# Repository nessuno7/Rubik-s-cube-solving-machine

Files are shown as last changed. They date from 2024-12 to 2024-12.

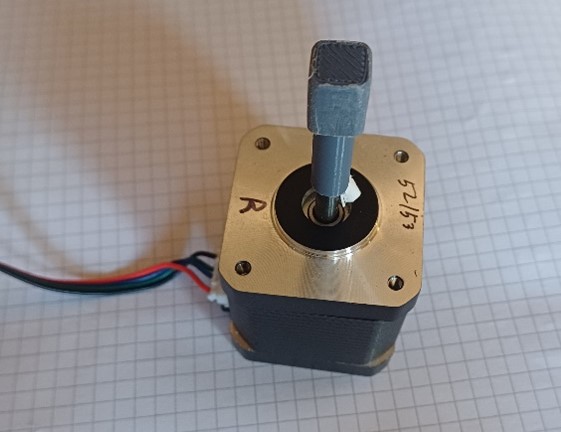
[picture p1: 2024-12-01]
CAD_design/motor_attachment_2.jpg

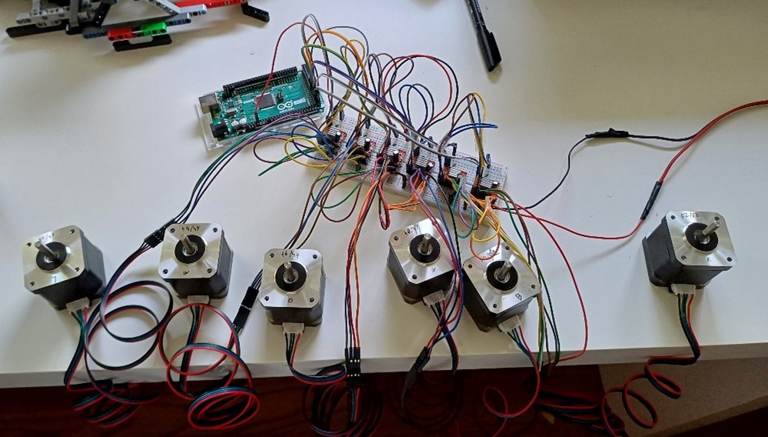
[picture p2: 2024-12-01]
Electronics/wiring_image.jpg

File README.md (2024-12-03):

# Rubik's cube solving machine
The machine solves the Rubik's cube by using the CFOP method, which method allows to solve any scrambled Rubik's cube with 60~100 moves. More information regarding the code in CFOP_algorithm/CFOP_readme.md\
\
The machine's structure is made of a Lego structure to hold the motors into place and 3D printed parts to attach the motors to the centre of the Rubik's cube. More information regarding the structure in CAD_design/CAD_readme.md\
\
The electronics of the machine consist of 6 stepper motors controlled with an Arduino Mega. More information regarding the electronics in Electronics/electronics_readme.md\
\
The code used for Arduino Mega is found in the Arduino_code folder. More information regarding the code in Arduino_code/arduino_readme.md\
\
The machine has two modes of use:
- The code gives prints a random scramble and the CFOP solution to such scramble to the terminal
- The user inputs all the colors of the already scrambles cube in a particular order, and the code prints the solution to the terminal

To run the machine, the Arduino_code needs to be run on an Arduino Mega, while the F2L algorithm needs to be run from the advanced_method.cpp file.\
On the arduino IDE the serial monitor has to be openend to copy and paste the move solutions from the terminal to the serial monitor.

Personal Info:
- name: Nicola Chiandetti
- email: nichiandetti@gmail.com

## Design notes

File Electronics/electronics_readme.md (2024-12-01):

# Electronics
The Rubik’s cube solving machine consist of 6 stepper motors controlled through the A4988 stepper motor driver and the Arduino Mega 2560 R3 board. The schematics of the circuits are shown in the Schematic_rubik-cube-machine.pdf file.\
\
Stepper motors were used as they provided very precise 90° and 180° turns. The model used is the NEMA 17 with 59 Ncm torque.\
\
Each driver needs two separate power supplies: 5V operating voltage with low current and 12V 2A max current for the motor. The VDD of the 6 drivers was connected in parallel with the Arduino 5V output. The VMOT of the 6 drivers was connected in parallel by an external power supply of 12V 10A (max). A capacitor (16V 100 uF) wired in parallel to each driver was also used to prevent voltage spikes to damage the driver and the motor. NEMA 17 59 Ncm has a max operating current of 2A, so the max current was adjusted to 1.8~1.5 A with the potentiometer screw.\
\
By using the A4988 stepper motor driver only two digital pins are needed to control each motor (one step pin and and one direction pin), meaning that only 12 digital pins are needed in total to control the whole machine. This makes it possible to operate the machine also with other small processors, such as the Arduino Uno.\
\
No PCB was used due to the cost of producing and shipping, the wiring is still on a breadboard.

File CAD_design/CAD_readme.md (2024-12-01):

# CAD design
The machine involves a Lego structure, built using Lego pieces from old Lego technic sets, that holds the 6 stepper motors together and 3D printed parts used to connect the stepper motors to the centre of the Cube.\
\
All 3D printed components were desgined using Fusion 360 and printed using PLA.\
The attachment for the cube was initially designed for the Original Rubik’s speed cube, however, after the cube was changed to another model, the attachment were attached to the new Rubik’s cube using superglue.\
The attachment for the motors was printed much longer than the actual lenght needed, and was then cut down to fit perfectly inside the structure to avoid printing the same part multiple times.

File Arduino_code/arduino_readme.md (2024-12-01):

# Arduino Code 
This code is used to control the Arduino Mega and reads a string of moves from the serial monitor and executes those moves.\
\
The move functions use a for() cycle to control the stepper motors into doing 50 steps for a 90° rotation or 100 steps for a 180° rotation. By setting the direction pin as high or low, the motor will rotate clockwise or anticlockwise.\
\
The delay between one step and the other is given by the acceleration_delay() function. This function allows the speed of the motor to be slower at the beginning of the rotation and then accelerate.\
\
The code also adds a delay between one move and the other of 100 milliseconds to avoid jamming. The delay is 0 only when the two moves are opposite each other.

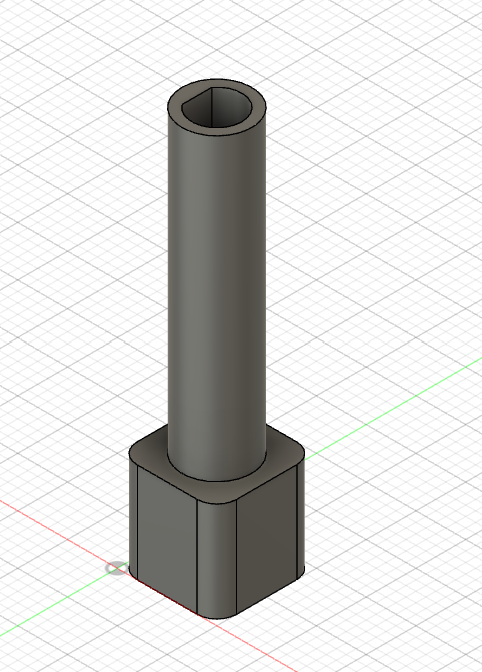
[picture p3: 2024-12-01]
CAD_design/motor_attachment_image.png

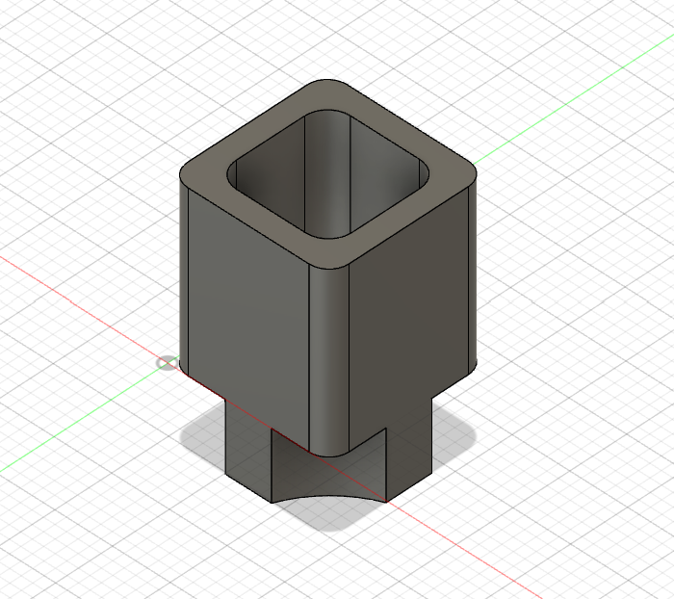
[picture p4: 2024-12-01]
CAD_design/Cube_attachment_image.png

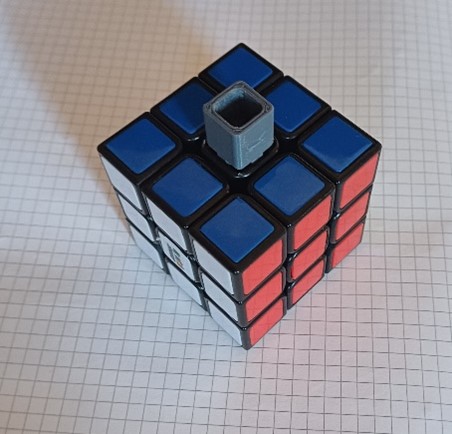
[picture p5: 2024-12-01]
CAD_design/cube_attachment_2.jpg

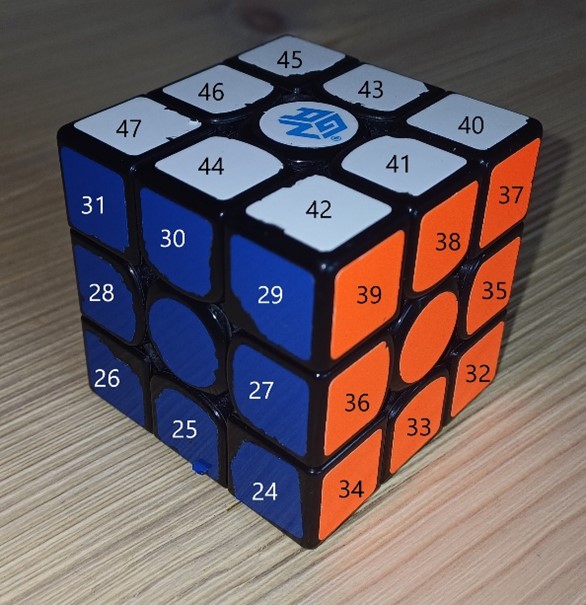
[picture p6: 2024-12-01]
CFOP_algorithm/images/color_array_2.jpg

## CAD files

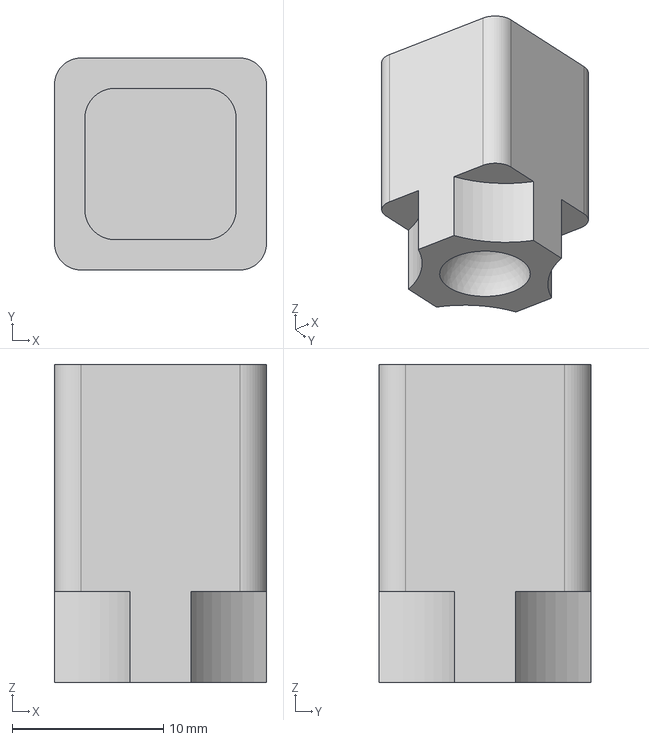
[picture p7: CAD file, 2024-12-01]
CAD_design/cube_attachment.step
14.0 x 14.0 x 21.0 mm

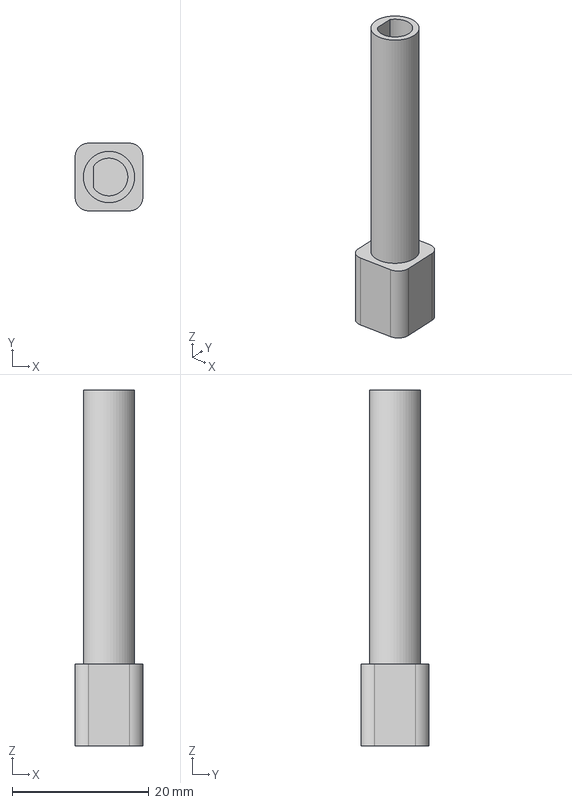
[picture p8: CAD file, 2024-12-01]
CAD_design/motor_attachment.step
9.90 x 9.90 x 52.0 mm

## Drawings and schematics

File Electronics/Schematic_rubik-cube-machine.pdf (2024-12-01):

A4988 L

A4988 R

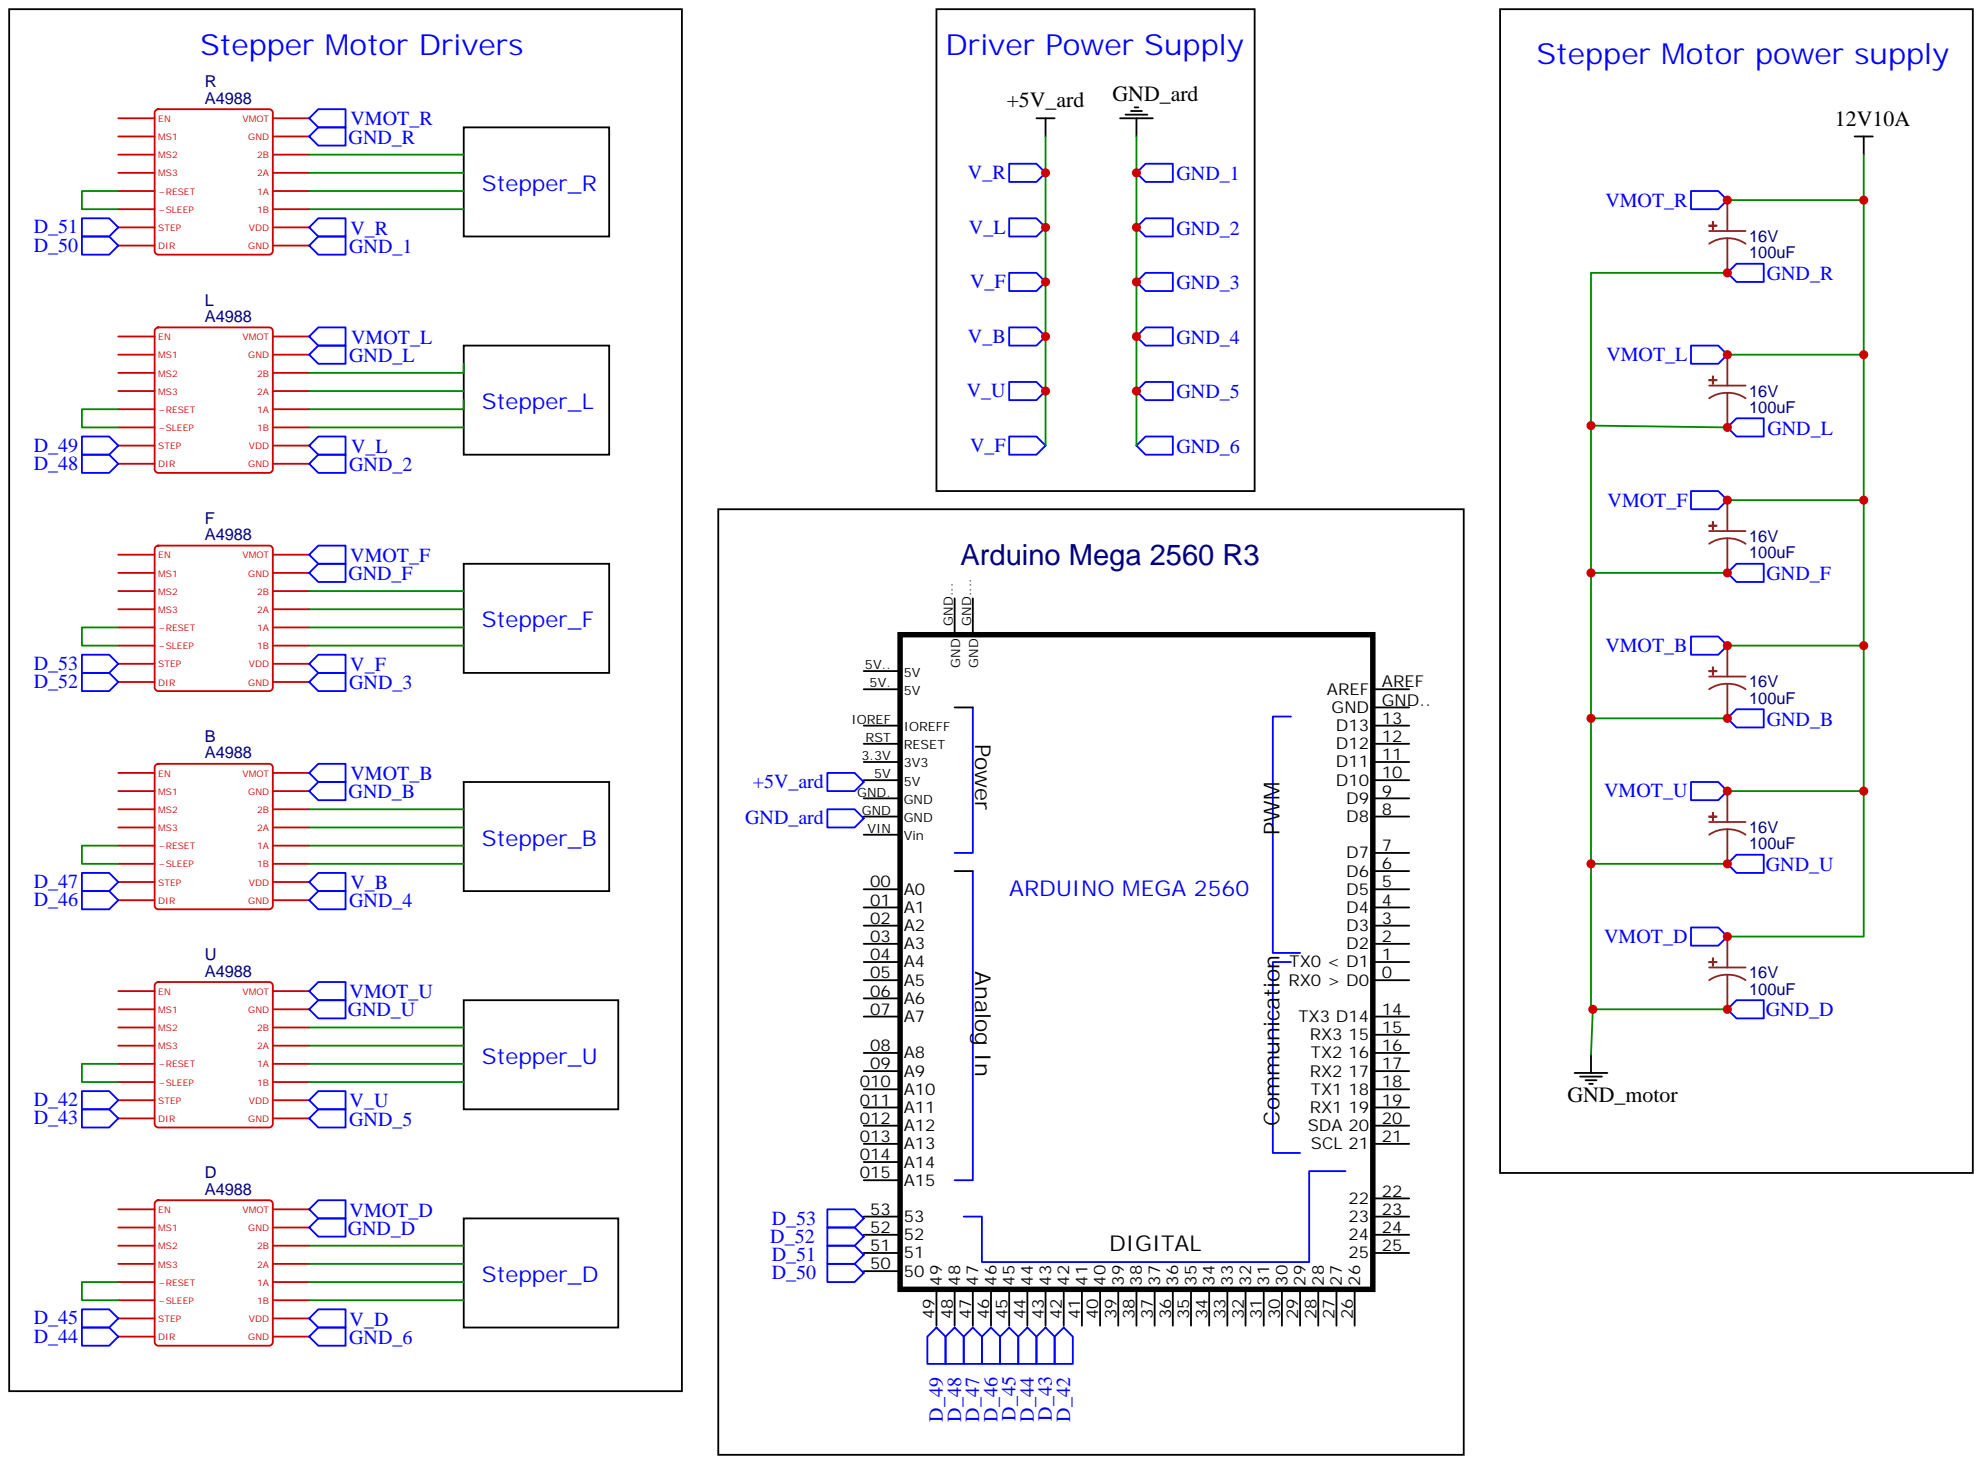
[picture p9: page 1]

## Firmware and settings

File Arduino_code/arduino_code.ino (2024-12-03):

//declares step and direction pins for each stepper motor
#define stepPinY 42
#define dirPinY 43
#define dirPinW 44
#define stepPinW 45
#define dirPinO 46
#define stepPinO 47
#define dirPinG 50
#define stepPinG 51
#define dirPinB 48
#define stepPinB 49
#define dirPinR 52
#define stepPinR 53


int dirPin = 0;
int stepPin = 0;
int minDelay = 1000;
const int rotationSpeedDelay = 1000;

/*
input: int i (between 0 ~ 50)
output: int delay in microseconds between two steps of the stepper motor
as the value of i increases the delay between steps is decreased, making the stepper motor rotate faster
*/
int acceleration_delay(int i){
  int return_ = 1250 - i*10;

  return return_;
}

/*
input: none
outout: void
controls the motors into doing a 90° (50 steps) or 180° (100 steps), either clockwise (step pin HIGH) or anticlockwise (step  pin LOW)
*/
void F_(){ //red face
  dirPin = dirPinR;
  stepPin = stepPinR;
  digitalWrite(dirPin, HIGH);

  for(int i = 0; i<50; i++){
    int delay = acceleration_delay(i);
    digitalWrite(stepPin, HIGH);
    delayMicroseconds(delay);
    digitalWrite(stepPin, LOW);
    delayMicroseconds(delay);
  }
}

void f_(){
  dirPin = dirPinR;
  stepPin = stepPinR;
  digitalWrite(dirPin, LOW);

  for(int i = 0; i<50; i++){
    int delay = acceleration_delay(i);
    digitalWrite(stepPin, HIGH);
    delayMicroseconds(delay);
    digitalWrite(stepPin, LOW);
    delayMicroseconds(delay);
  }
}

void F2(){
  dirPin = dirPinR;
  stepPin = stepPinR;
  digitalWrite(dirPin, HIGH);

  for(int i = 0; i<100; i++){
    digitalWrite(stepPin, HIGH);
    delayMicroseconds(rotationSpeedDelay);
    digitalWrite(stepPin, LOW);
    delayMicroseconds(rotationSpeedDelay);
  }
}

void L_(){ //green face
  dirPin = dirPinG;
  stepPin = stepPinG;
  digitalWrite(dirPin, HIGH);

  for(int i = 0; i<50; i++){
    int delay = acceleration_delay(i);
    digitalWrite(stepPin, HIGH);
    delayMicroseconds(delay);
    digitalWrite(stepPin, LOW);
    delayMicroseconds(delay);
  }
}

void l_(){
  dirPin = dirPinG;
  stepPin = stepPinG;
  digitalWrite(dirPin, LOW);

  for(int i = 0; i<50; i++){
    int delay = acceleration_delay(i);
    digitalWrite(stepPin, HIGH);
    delayMicroseconds(delay);
    digitalWrite(stepPin, LOW);
    delayMicroseconds(delay);
  }
}

void L2(){
  dirPin = dirPinG;
  stepPin = stepPinG;
  digitalWrite(dirPin, LOW);

  for(int i = 0; i<100; i++){
    digitalWrite(stepPin, HIGH);
    delayMicroseconds(rotationSpeedDelay);
    digitalWrite(stepPin, LOW);
    delayMicroseconds(rotationSpeedDelay);
  }
}

void R_(){ //blue face
  dirPin = dirPinB;
  stepPin = stepPinB;
  digitalWrite(dirPin, HIGH);

  for(int i = 0; i<50; i++){
    int delay = acceleration_delay(i);
    digitalWrite(stepPin, HIGH);
    delayMicroseconds(delay);
    digitalWrite(stepPin, LOW);
    delayMicroseconds(delay);
  }
}

void r_(){
  dirPin = dirPinB;
  stepPin = stepPinB;
  digitalWrite(dirPin, LOW);

  for(int i = 0; i<50; i++){
    int delay = acceleration_delay(i);
    digitalWrite(stepPin, HIGH);
    delayMicroseconds(delay);
    digitalWrite(stepPin, LOW);
    delayMicroseconds(delay);
  }
}

void R2(){
  dirPin = dirPinB;
  stepPin = stepPinB;
  digitalWrite(dirPin, HIGH);

  for(int i = 0; i<100; i++){
    digitalWrite(stepPin, HIGH);
    delayMicroseconds(rotationSpeedDelay);
    digitalWrite(stepPin, LOW);
    delayMicroseconds(rotationSpeedDelay);
  }
}

void B_(){ //orange face
  dirPin = dirPinO;
  stepPin = stepPinO;
  digitalWrite(dirPin, HIGH);

  for(int i = 0; i<50; i++){
    int delay = acceleration_delay(i);
    digitalWrite(stepPin, HIGH);
    delayMicroseconds(delay);
    digitalWrite(stepPin, LOW);
    delayMicroseconds(delay);
  }
}

void b_(){
  dirPin = dirPinO;
  stepPin = stepPinO;
  digitalWrite(dirPin, LOW);

  for(int i = 0; i<50; i++){
    int delay = acceleration_delay(i);
    digitalWrite(stepPin, HIGH);
    delayMicroseconds(delay);
    digitalWrite(stepPin, LOW);
    delayMicroseconds(delay);
  }
}

void B2(){
  dirPin = dirPinO;
  stepPin = stepPinO;
  digitalWrite(dirPin, LOW);

  for(int i = 0; i<100; i++){
    digitalWrite(stepPin, HIGH);
    delayMicroseconds(rotationSpeedDelay);
    digitalWrite(stepPin, LOW);
    delayMicroseconds(rotationSpeedDelay);
  }
}

void U_(){ //yellow face
  dirPin = dirPinY;
  stepPin = stepPinY;
  digitalWrite(dirPin, HIGH);

  for(int i = 0; i<50; i++){
    int delay = acceleration_delay(i);
    digitalWrite(stepPin, HIGH);
    delayMicroseconds(delay);
    digitalWrite(stepPin, LOW);
    delayMicroseconds(delay);
  }
}

void u_(){
  dirPin = dirPinY;
  stepPin = stepPinY;
  digitalWrite(dirPin, LOW);

  for(int i = 0; i<50; i++){
    int delay = acceleration_delay(i);
    digitalWrite(stepPin, HIGH);
    delayMicroseconds(delay);
    digitalWrite(stepPin, LOW);
    delayMicroseconds(delay);
  }
}

void U2(){
  dirPin = dirPinY;
  stepPin = stepPinY;
  digitalWrite(dirPin, HIGH);

  for(int i = 0; i<100; i++){
    digitalWrite(stepPin, HIGH);
    delayMicroseconds(rotationSpeedDelay);
    digitalWrite(stepPin, LOW);
    delayMicroseconds(rotationSpeedDelay);
  }
}

void D_(){ //white face
  dirPin = dirPinW;
  stepPin = stepPinW;
  digitalWrite(dirPin, HIGH);

  for(int i = 0; i<50; i++){
    int delay = acceleration_delay(i);
    digitalWrite(stepPin, HIGH);
    delayMicroseconds(delay);
    digitalWrite(stepPin, LOW);
    delayMicroseconds(delay);
  }
}

void d_(){
  dirPin = dirPinW;
  stepPin = stepPinW;
  digitalWrite(dirPin, LOW);

  for(int i = 0; i<50; i++){
    int delay = acceleration_delay(i);
    digitalWrite(stepPin, HIGH);
    delayMicroseconds(delay);
    digitalWrite(stepPin, LOW);
    delayMicroseconds(delay);
  }
}

void D2(){
  dirPin = dirPinW;
  stepPin = stepPinW;
  digitalWrite(dirPin, LOW);

  for(int i = 0; i<100; i++){
    digitalWrite(stepPin, HIGH);
    delayMicroseconds(rotationSpeedDelay);
    digitalWrite(stepPin, LOW);
    delayMicroseconds(rotationSpeedDelay);
  }
}

/*
input: none
output: void
setting all pins at output
*/
void setup() {
  pinMode(stepPinR, OUTPUT);
  pinMode(dirPinR, OUTPUT);
  pinMode(stepPinB, OUTPUT);
  pinMode(dirPinB, OUTPUT);
  pinMode(stepPinG, OUTPUT);
  pinMode(dirPinG, OUTPUT);
  pinMode(stepPinO, OUTPUT);
  pinMode(dirPinO, OUTPUT);
  pinMode(stepPinW, OUTPUT);
  pinMode(dirPinW, OUTPUT);
  pinMode(stepPinY, OUTPUT);
  pinMode(dirPinY, OUTPUT);

  Serial.begin(9600);
}

/*
input: two consecutive moves from the move array
output: bool
if the moves are in opposite faces, function returns true and the delay between these two moves will be 0
*/
bool is_opposite(String move1, String move2){
  if((move1 == "R" || move1 == "r" || move1 == "2R") && (move2 == "L" || move2 == "l" || move2 == "2L")){
    return true;
  }
  if((move1 == "L" || move1 == "l" || move1 == "2L") && (move2 == "R" || move2 == "r" || move2 == "2R")){
    return true;
  }
  if((move1 == "B" || move1 == "b" || move1 == "2B") && (move2 == "F" || move2 == "f" || move2 == "2F")){
    return true;
  }
  if((move1 == "F" || move1 == "f" || move1 == "2F") && (move2 == "B" || move2 == "b" || move2 == "2B")){
    return true;
  }
  if((move1 == "U" || move1 == "u" || move1 == "2U") && (move2 == "D" || move2 == "d" || move2 == "2D")){
    return true;
  }
  if((move1 == "D" || move1 == "d" || move1 == "2D") && (move2 == "U" || move2 == "u" || move2 == "2U")){
    return true;
  }

  return false;
}

/*
input: string move
output: void
executes the move calling the right function corresponding to the move string
*/
void execute_move(String move){
  if(move == "R"){
    R_();
  }
  else if(move == "r"){
    r_();
  }
  else if(move == "2R"){
    R2();
  }
  else if(move == "L"){
    L_();
  }
  else if(move == "l"){
    l_();
  }
  else if(move == "2L"){
    L2();
  }
  else if(move == "F"){
    F_();
  }
  else if(move == "f"){
    f_();
  }
  else if(move == "2F"){
    F2();
  }
  else if(move == "B"){
    B_();
  }
  else if(move == "b"){
    b_();
  }
  else if(move == "2B"){
    B2();
  }
  else if(move == "U"){
    U_();
  }
  else if(move == "u"){
    u_();
  }
  else if(move == "2U"){
    U2();
  }
  else if(move == "D"){
    D_();
  }
  else if(move == "d"){
    d_();
  }
  else if(move == "2D"){
    D2();
  }
  else{
    Serial.println("Error: move not recognised");
  }
}

/*
input: array of String moves, int number of moves (dimension of array) 
output: void
for cycle that executes every move of the array, delay between moves is 0 only when is_opposite() is true, while delay is 100
*/
void execute_moves(String moves[], int numberMoves){
  for(int i=0; i<numberMoves; i++){
    if(moves[i] != " "){
      execute_move(moves[i]);
      Serial.println(moves[i]);

      if(is_opposite(moves[i], moves[i+1])){
        delay(0);
      }
      else{
        delay(100);
      }
    }
  }
}

/*
input: none
output: void
Serial monitor waits until it receives an input of moves. The string with all the moves is then divided into the singles strings that make the moves_to_do[] array. All these moves are then executed.
*/
void loop() {
  while (Serial.available() == 0) {}
  String moves = Serial.readString();
  moves.trim();

  int dimension = moves.length(); 
  String moves_to_do[dimension];
  for(int i = 0; i < dimension; i++){
    moves_to_do[i] = " ";
  }

  int index = 0;

  for (int i = 0; i < moves.length(); i++){
    char appo = moves.charAt(i);
    bool previous_is_2;

    if(appo != " "){
      if(appo == '2'){
        previous_is_2 = true;
      }
      else{
        switch(appo){
          case 'R':
            if(previous_is_2 == true){
              moves_to_do[index] = "2R";
            }
            else{
              moves_to_do[index] = "R";
            }
            break;

          case'r':
            moves_to_do[index] = "r";
            break;

          case 'L':
            if(previous_is_2 == true){
              moves_to_do[index] = "2L";
            }
            else{
              moves_to_do[index] = "L";
            }
            break;

          case 'l':
            moves_to_do[index] = "l";
            break;

          case 'F':
            if(previous_is_2 == true){
              moves_to_do[index] = "2F";
            }
            else{
              moves_to_do[index] = "F";
            }
            break;

          case 'f':
            moves_to_do[index] = "f";
            break;          
          
          case 'B':
            if(previous_is_2 == true){
              moves_to_do[index] = "2B";
            }
            else{
              moves_to_do[index] = "B";
            }
            break;          
          
          case 'b':
            moves_to_do[index] = "b";
            break;          
          
          case 'U':
            if(previous_is_2 == true){
              moves_to_do[index] = "2U";
            }
            else{
              moves_to_do[index] = "U";
            }
            break;          
          
          case 'u':
            moves_to_do[index] = "u";
            break;          
          
          case 'D':
            if(previous_is_2 == true){
              moves_to_do[index] = "2D";
            }
            else{
              moves_to_do[index] = "D";
            }
            break;          
          
          case 'd':
            moves_to_do[index] = "d";
            break;
        }
        index++;
        previous_is_2 = false;
      }
    }
  }

  for(int i =0; i<dimension; i++){
    Serial.print(moves_to_do[i]);
    Serial.print(" ");
  }

  execute_moves(moves_to_do, dimension);

}
